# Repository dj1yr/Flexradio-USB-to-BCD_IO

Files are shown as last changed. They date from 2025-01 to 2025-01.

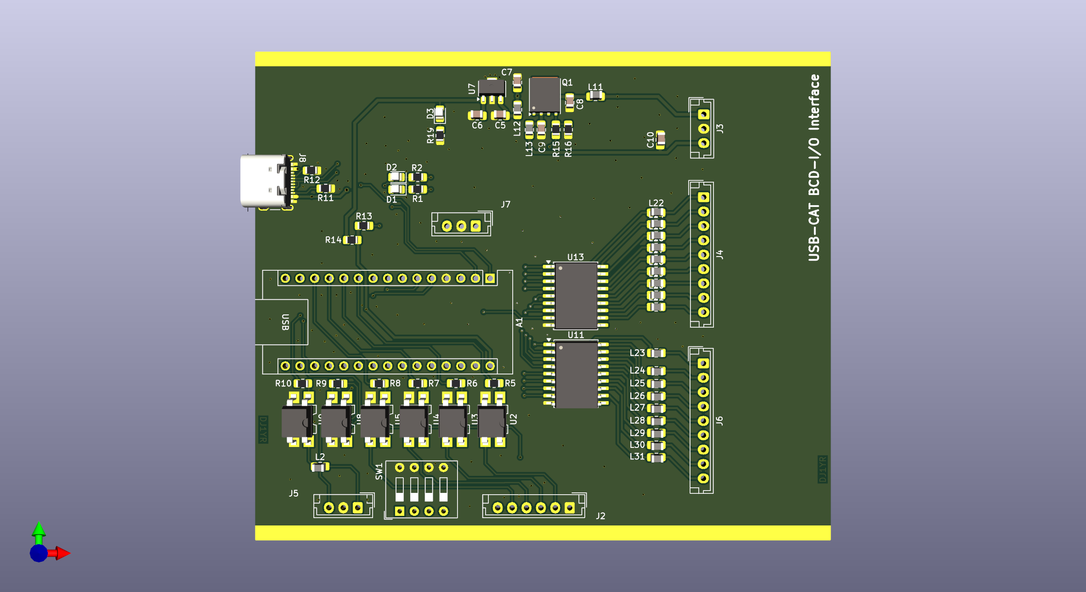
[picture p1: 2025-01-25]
Flexradio USB to BCD IO_top.png

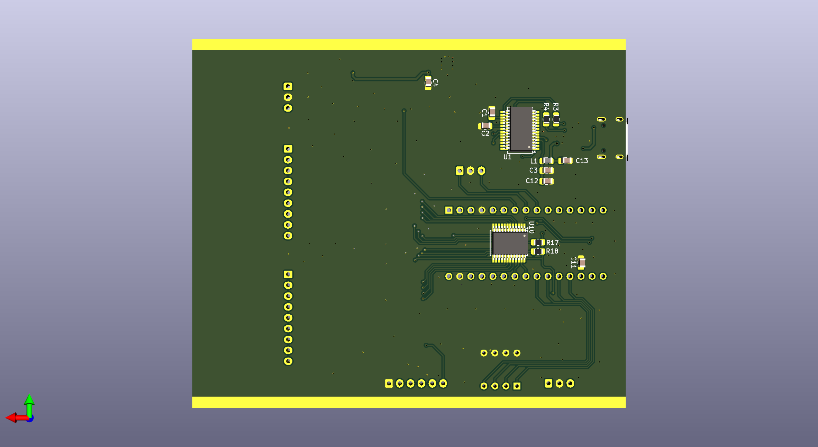
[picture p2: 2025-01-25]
Flexradio USB to BCD IO_bottom.png

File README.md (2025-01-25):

Since Flexradio does not output any band data from the device, the Flexwire bus unfortunately does not work. (is not implemented by Flex)
I have created a circuit board which adapts the USB signal to TTL to the Arduino Every.
The Flexradio only recognizes FTDI converters!
The board has BCD out, TXin and TXout, as well as 16 I/O via PCF8575 for other functions.
I need the board to control my VL-1000.

The software is currently under development and so far only reads and selects the data.

73' René

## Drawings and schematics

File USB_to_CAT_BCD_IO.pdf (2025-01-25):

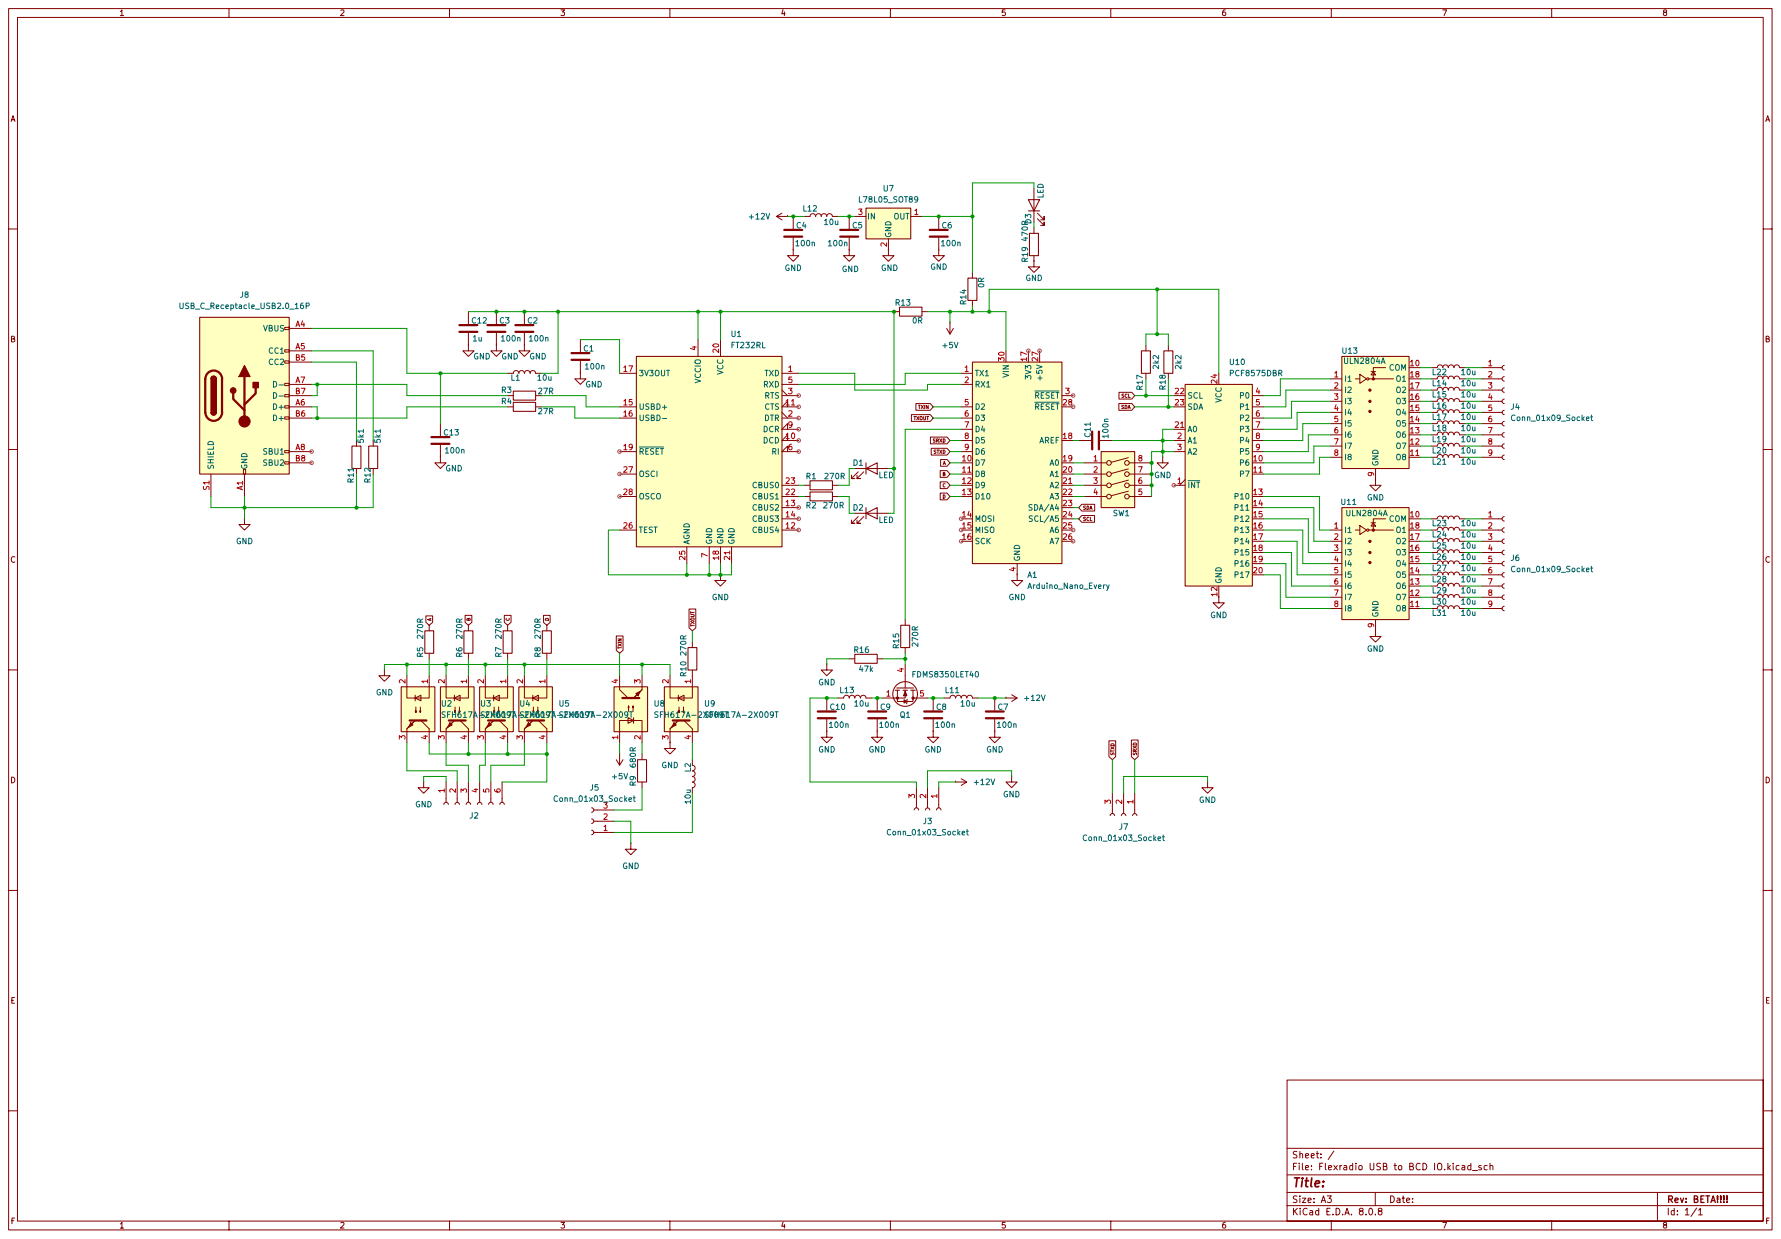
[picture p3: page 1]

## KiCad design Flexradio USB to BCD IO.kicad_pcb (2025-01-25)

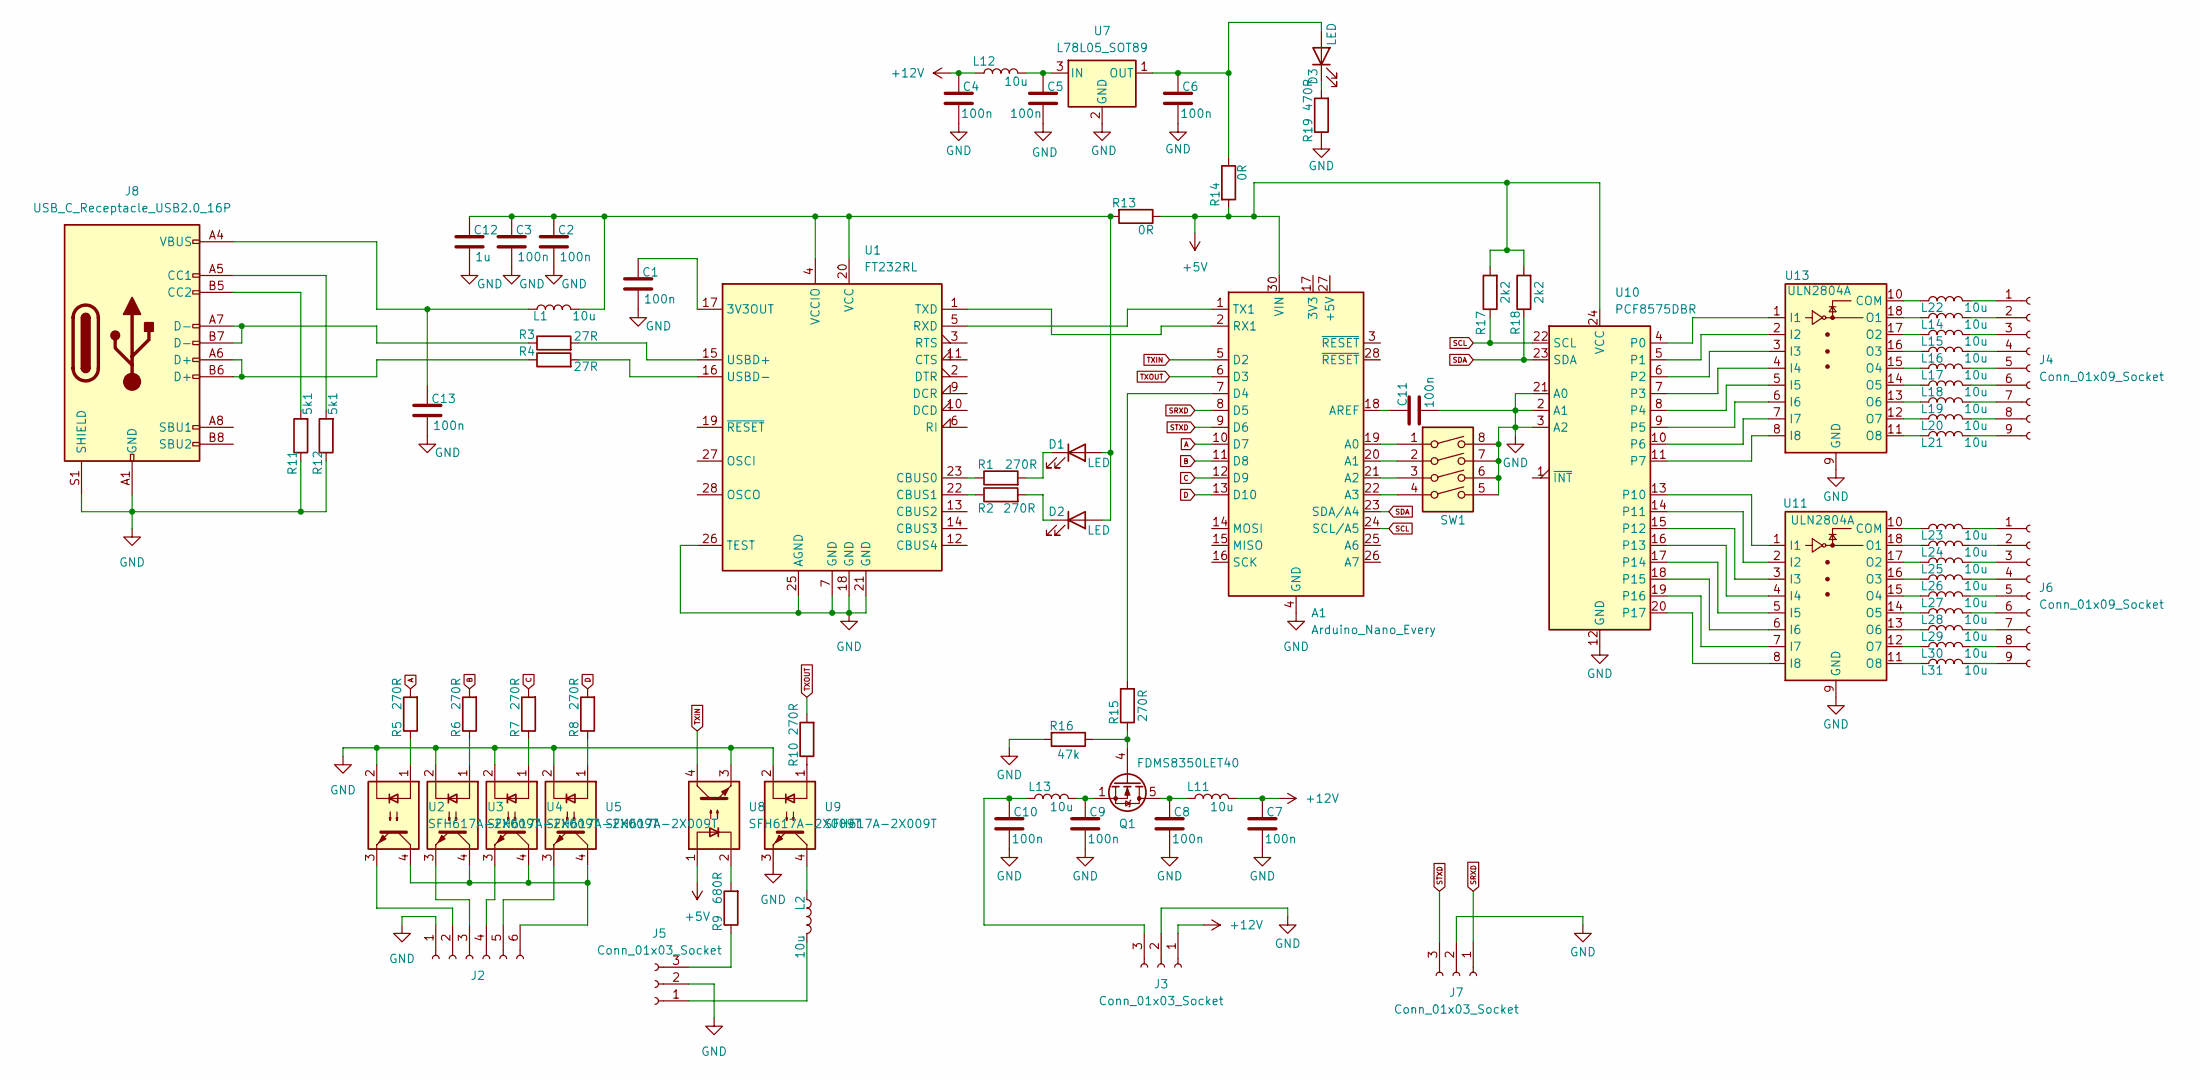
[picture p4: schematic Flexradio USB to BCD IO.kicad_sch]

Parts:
A1: Arduino_Nano_Every; Arduino_Nano
C1, C2, C3, C4, C5, C6, C7, C8, C9, C10, C11, C13: 100n; C_0805_2012Metric_Pad1.18x1.45mm_HandSolder
C12: 1u; C_0805_2012Metric_Pad1.18x1.45mm_HandSolder
D1, D2, D3: LED; LED_0805_2012Metric
J2: Conn_01x06_Socket; JST_EH_B6B-EH-A_1x06_P2.50mm_Vertical
J3, J5, J7: Conn_01x03_Socket; JST_EH_B3B-EH-A_1x03_P2.50mm_Vertical
J4, J6: Conn_01x09_Socket; JST_EH_B9B-EH-A_1x09_P2.50mm_Vertical
J8: USB_C_Receptacle_USB2.0_16P; USB_C_Receptacle_GCT_USB4105-xx-A_16P_TopMnt_Horizontal
L1, L2, L11, L12, L13, L14, L15, L16, L17, L18, L19, L20, L21, L22, L23, L24, L25, L26, L27, L28, L29, L30, L31: 10u; L_0805_2012Metric_Pad1.15x1.40mm_HandSolder
Q1: FDMS8350LET40; TDSON-8-1
R1, R2, R5, R6, R7, R8, R10, R15: 270R; R_0805_2012Metric_Pad1.20x1.40mm_HandSolder
R3, R4: 27R; R_0805_2012Metric_Pad1.20x1.40mm_HandSolder
R9: 680R; R_0805_2012Metric_Pad1.20x1.40mm_HandSolder
R11, R12: 5k1; R_0805_2012Metric_Pad1.20x1.40mm_HandSolder
R13, R14: 0R; R_0805_2012Metric_Pad1.20x1.40mm_HandSolder
R16: 47k; R_0805_2012Metric_Pad1.20x1.40mm_HandSolder
R17, R18: 2k2; R_0805_2012Metric_Pad1.20x1.40mm_HandSolder
R19: 470R; R_0805_2012Metric_Pad1.20x1.40mm_HandSolder
SW1: SW_DIP_x04; SW_DIP_SPSTx04_Slide_9.78x12.34mm_W7.62mm_P2.54mm
U1: FT232RL; SSOP-28_5.3x10.2mm_P0.65mm
U2, U3, U4, U5, U8, U9: SFH617A-2X009T; SMDIP-4_W7.62mm
U7: L78L05_SOT89; SOT-89-3
U10: PCF8575DBR; SSOP-24_5.3x8.2mm_P0.65mm
U11, U13: ULN2804A; SOIC-18W_7.5x11.6mm_P1.27mm

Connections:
+5V: A1.30 (VIN), R13.1, R14.2, R17.2, R18.2, U8.1, U10.24 (VCC)
+12V: C4.1, C7.1, J3.1, L11.2, L12.1
A: A1.10 (D7), R5.2
B: A1.11 (D8), R6.2
C: A1.12 (D9), R7.2
D: A1.13 (D10), R8.2
GND: A1.4 (GND), A1.29 (GND), C1.2, C2.2, C3.2, C4.2, C5.2, C6.2, C7.2, C8.2, C9.2, C10.2, C11.2, C12.2, C13.2, J2.1, J3.2, J5.2, J7.2, J8.A1 (GND), J8.A12 (GND), J8.B1 (GND), J8.B12 (GND), J8.S1 (SHIELD), R11.1, R12.1, R16.2, R19.1, SW1.5, SW1.6, SW1.7, SW1.8, U1.7 (GND), U1.18 (GND), U1.21 (GND), U1.25 (AGND), U1.26 (TEST), U2.2, U3.2, U4.2, U5.2, U7.2 (GND), U8.3, U9.2, U9.3, U10.2 (A1), U10.3 (A2), U10.12 (GND), U10.21 (A0), U11.9 (GND), U13.9 (GND)
unnamed: A1.19 (A0), SW1.1
unnamed: A1.20 (A1), SW1.2
unnamed: A1.21 (A2), SW1.3
unnamed: A1.22 (A3), SW1.4
unnamed: A1.18 (AREF), C11.1
unnamed: A1.7 (D4), R15.2
unnamed: A1.2 (RX1), U1.1 (TXD)
unnamed: A1.1 (TX1), U1.5 (RXD)
unnamed: C9.1, L13.2, Q1.1 (S), Q1.2 (S), Q1.3 (S)
unnamed: C13.1, J8.A4 (VBUS), J8.A9 (VBUS), J8.B4 (VBUS), J8.B9 (VBUS), L1.1
unnamed: C2.1, C3.1, C12.1, D1.2 (A), D2.2 (A), L1.2, R13.2, U1.4 (VCCIO), U1.20 (VCC)
unnamed: D1.1 (K), R1.2
unnamed: D2.1 (K), R2.2
unnamed: C6.1, D3.2 (A), R14.1, U7.1 (OUT)
unnamed: D3.1 (K), R19.2
unnamed: J2.2, U2.3
unnamed: J2.3, U3.3
unnamed: J2.4, U4.3
unnamed: J2.5, U5.3
unnamed: J2.6, U2.4, U3.4, U4.4, U5.4
unnamed: C10.1, J3.3, L13.1
unnamed: J4.1, L22.2
unnamed: J4.2, L14.2
unnamed: J4.3, L15.2
unnamed: J4.4, L16.2
unnamed: J4.5, L17.2
unnamed: J4.6, L18.2
unnamed: J4.7, L19.2
unnamed: J4.8, L20.2
unnamed: J4.9, L21.2
unnamed: J5.1, L2.2
unnamed: J5.3, R9.1
unnamed: J6.1, L23.2
unnamed: J6.2, L24.2
unnamed: J6.3, L25.2
unnamed: J6.4, L26.2
unnamed: J6.5, L27.2
unnamed: J6.6, L28.2
unnamed: J6.7, L29.2
unnamed: J6.8, L30.2
unnamed: J6.9, L31.2
unnamed: J8.A5 (CC1), R12.2
unnamed: J8.B5 (CC2), R11.2
unnamed: J8.A6 (D+), J8.B6 (D+), R4.1
unnamed: J8.A7 (D-), J8.B7 (D-), R3.1
unnamed: L2.1, U9.4
unnamed: C8.1, L11.1, Q1.5 (D)
unnamed: Q1.4 (G), R15.1, R16.1
unnamed: R5.1, U2.1
unnamed: R6.1, U3.1
unnamed: R7.1, U4.1
unnamed: R8.1, U5.1
unnamed: R9.2, U8.2
unnamed: R10.1, U9.1
unnamed: C1.1, U1.17 (3V3OUT)
unnamed: R1.1, U1.23 (CBUS0)
unnamed: R2.1, U1.22 (CBUS1)
unnamed: R3.2, U1.15 (USBD+)
unnamed: R4.2, U1.16 (USBD-)
unnamed: C5.1, L12.2, U7.3 (IN)
unnamed: U10.4 (P0), U13.1 (I1)
unnamed: U10.5 (P1), U13.2 (I2)
unnamed: U10.6 (P2), U13.3 (I3)
unnamed: U10.7 (P3), U13.4 (I4)
unnamed: U10.8 (P4), U13.5 (I5)
unnamed: U10.9 (P5), U13.6 (I6)
unnamed: U10.10 (P6), U13.7 (I7)
unnamed: U10.11 (P7), U13.8 (I8)
unnamed: U10.13 (P10), U11.1 (I1)
unnamed: U10.14 (P11), U11.2 (I2)
unnamed: U10.15 (P12), U11.3 (I3)
unnamed: U10.16 (P13), U11.4 (I4)
unnamed: U10.17 (P14), U11.5 (I5)
unnamed: U10.18 (P15), U11.6 (I6)
unnamed: U10.19 (P16), U11.7 (I7)
unnamed: U10.20 (P17), U11.8 (I8)
unnamed: L23.1, U11.10 (COM)
unnamed: L24.1, U11.18 (O1)
unnamed: L25.1, U11.17 (O2)
unnamed: L26.1, U11.16 (O3)
unnamed: L27.1, U11.15 (O4)
unnamed: L28.1, U11.14 (O5)
unnamed: L29.1, U11.13 (O6)
unnamed: L30.1, U11.12 (O7)
unnamed: L31.1, U11.11 (O8)
unnamed: L22.1, U13.10 (COM)
unnamed: L14.1, U13.18 (O1)
unnamed: L15.1, U13.17 (O2)
unnamed: L16.1, U13.16 (O3)
unnamed: L17.1, U13.15 (O4)
unnamed: L18.1, U13.14 (O5)
unnamed: L19.1, U13.13 (O6)
unnamed: L20.1, U13.12 (O7)
unnamed: L21.1, U13.11 (O8)
SCL: A1.24 (SCL/A5), R17.1, U10.22 (SCL)
SDA: A1.23 (SDA/A4), R18.1, U10.23 (SDA)
SRXD: A1.8 (D5), J7.1
STXD: A1.9 (D6), J7.3
TXIN: A1.5 (D2), U8.4
TXOUT: A1.6 (D3), R10.2

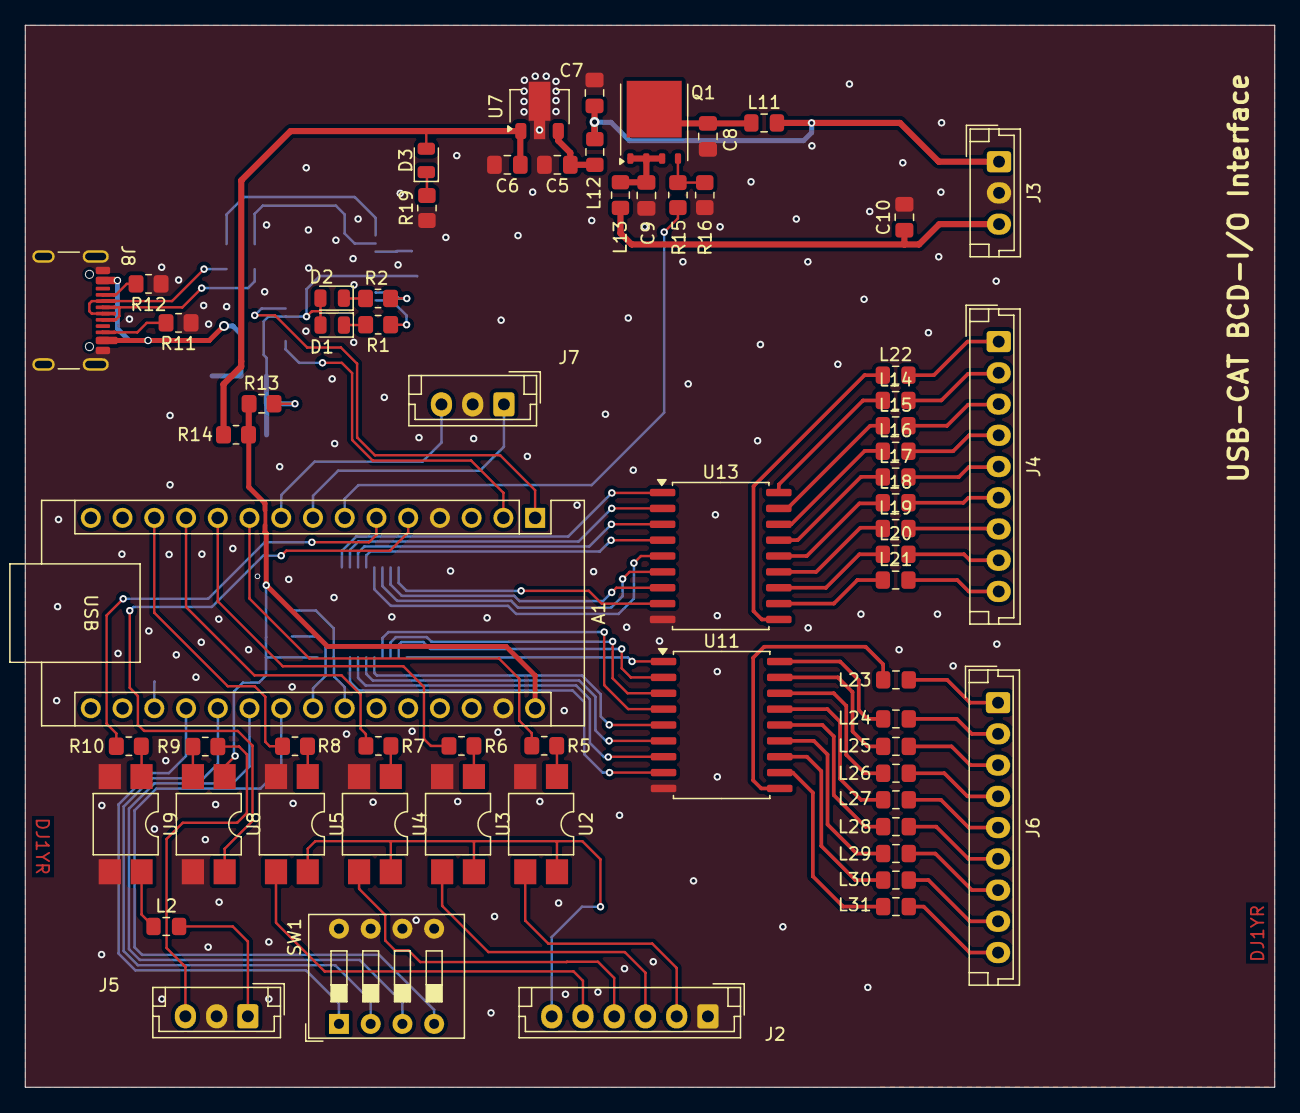
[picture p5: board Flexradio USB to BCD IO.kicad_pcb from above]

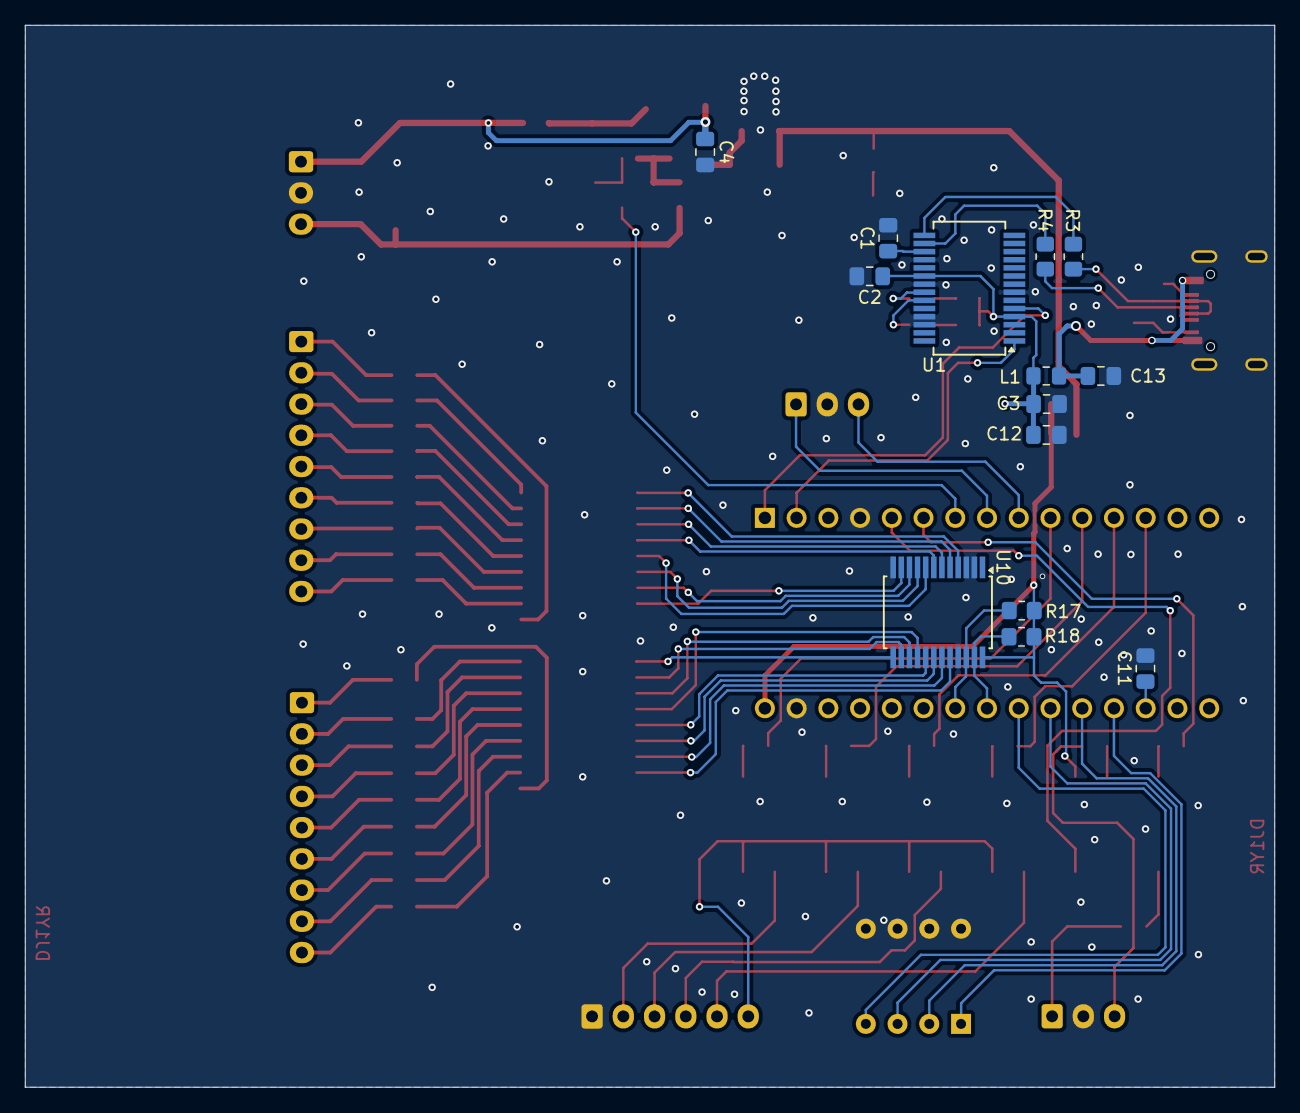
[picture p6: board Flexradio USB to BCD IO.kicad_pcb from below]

Board: 2 copper layers, 100.0 x 85.0 mm, 79 parts (14 on the bottom side), 107 nets.

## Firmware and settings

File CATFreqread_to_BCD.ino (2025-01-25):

/* this software is alpha!!
only CAT Data read from Flex 6x00
*/


#include "Arduino.h"
#include "PCF8575.h"          // https://github.com/xreef/PCF8575_library
#include <SoftwareSerial.h>

SoftwareSerial cat_ser(5, 6); // RX, TX

PCF8575 pcf8575(0x20);


char inputByte;  
String inputbuffer = "";  
bool readComplete = false; 

byte band = 9;
int A = 7;
int B = 8;
int C = 9;
int D = 10; 

bool TX_in = 2;
bool TX_out = 3;
int TX_ok = false;

bool pcf_a0;
bool pcf_a1;
bool pcf_a2;
bool pcf_a3;
bool pcf_a4;
bool pcf_a5;
bool pcf_a6;
bool pcf_a7;

bool pcf_b0;
bool pcf_b1;
bool pcf_b2;
bool pcf_b3;
bool pcf_b4;
bool pcf_b5;
bool pcf_b6;
bool pcf_b7;
byte pcf_a;
byte pcf_b;

byte bcdoutputPins[] {7,8,9,10};

/*byte yaesu_bcd [16][4]={   //BCD table -- yaesu_bcd [band][A,B,C;D]
{0,0,0,0},
{0,0,0,1},    //160m
{0,0,1,0},    //80m
{0,0,1,1},    //60/40m
{0,1,0,0},    //30m
{0,1,0,1},    //20m
{0,1,1,0},    //17m
{0,1,1,1},    //15m
{1,0,0,0},    //12m
{1,0,0,1},    //10m
{1,0,1,0},    //6m
{1,0,1,1},    //4m
{1,1,0,0},    //2m
{1,1,0,1},    //70cm
{1,1,1,0},    //23cm
{1,1,1,1},
};*/



float yaesu_bcd [16][4]={   //BCD table -- yaesu_bcd [band][A,B,C;D]
{A=0,B=0,C=0,D=0},
{A=0,B=0,C=0,D=1},    //160m
{A=0,B=0,C=1,D=0},    //80m
{A=0,B=0,C=1,D=1},    //60/40m
{A=0,B=1,C=0,D=0},    //30m
{A=0,B=1,C=0,D=1},    //20m
{A=0,B=1,C=1,D=0},    //17m
{A=0,B=1,C=1,D=1},    //15m
{A=1,B=0,C=0,D=0},    //12m
{A=1,B=0,C=0,D=1},    //10m
{A=1,B=0,C=1,D=0},    //6m
{A=1,B=0,C=1,D=1},    //4m
{A=1,B=1,C=0,D=0},    //2m
{A=1,B=1,C=0,D=1},    //70cm
{A=1,B=1,C=1,D=0},    //23cm
{A=1,B=1,C=1,D=1},
};

void setup(){
  Serial.begin(9600);       //Debug Serial
  Serial1.begin(9600);      //CAT Serial Flex
  cat_ser.begin(9600);      //CAT Serial optional

// pinMode BCD
  pinMode(A, OUTPUT);
  pinMode(B, OUTPUT);
  pinMode(C, OUTPUT);
  pinMode(D, OUTPUT);
//  pinMode TX
  pinMode(TX_in, INPUT_PULLUP);
  pinMode(TX_out, OUTPUT); 
// PCF8575
  // Set pinMode to OUTPUT
  for(int i=0;i<16;i++) {
    pcf8575.pinMode(i, OUTPUT);
  }
  pcf8575.begin();

}   //end setup

void loop() {


      if (Serial1.available() > 0) {
        inputByte = (char) Serial1.read(); 
        inputbuffer += inputByte; 
        if (inputByte == ';') {
        readComplete = true; 
        }
      }

    
    if (readComplete) {
        String input_str = inputbuffer;
        String freq ;
        freq = input_str.substring(4,13);


    if (freq>= "470000000"){          // 23cm Band selcted
      band = 14;
      bcdoutputPins[4] = band;}
          else if (freq >= "150000000"){  // 70cm Band selcted
        band = 13;
        bcdoutputPins[4] = band;}  
      else if (freq >= "074000000"){  // 2m Band selcted
        band = 12;
        bcdoutputPins[4] = band;}      
      else if (freq >= "054000000"){  // 4m Band selcted
        band = 11;
        bcdoutputPins[4] = band;}      
      else if (freq >= "030000000"){  // 6m Band selcted
        band = 10;
        bcdoutputPins[4] = band;}
      else if (freq >= "028000000"){  // 10m Band selcted
        band = 9;
        bcdoutputPins[4] = band;}        
      else if (freq >= "024000000"){  // 12 Band selcted
        band = 8;
        bcdoutputPins[4] = band;}
      else if (freq >= "020000000"){  // 15m Band selcted
        band = 7;
        bcdoutputPins[4] = band;}
      else if (freq >= "015000000"){  // 17m Band selcted  
        band = 6;
        bcdoutputPins[4] = band;}
      else if (freq >= "012000000"){  // 20m Band selcted
        band = 5;
        bcdoutputPins[4] = band;}        
      else if (freq >= "009000000"){  // 30 Band selcted
        band = 4;
        bcdoutputPins[4] = band;}
      else if (freq >= "005000000"){  // 60/40m Band selcted
        band = 3;
        bcdoutputPins[4] = band;}
      else if (freq >= "002000000"){  // 80m Band selcted
        band = 2;
        bcdoutputPins[4] = band;}
      else if (freq >= "001700000"){  // 160m Band selcted
        band = 1;
        bcdoutputPins[4] = band;}        
      else {
        band = 0;
        bcdoutputPins[4] = band;}                    // no Band selcted  

        Serial.print("freq_Hz=");
        Serial.println(freq);
        Serial.print("Band=");
        Serial.println(band);
        Serial.print("Outputbyte=");
        Serial.println(bcdoutputPins[4], BIN);
        Serial.flush();
        pcf8575_write();
        
        inputbuffer = "";
        readComplete = false; 
      }

    if (band = 0){
        TX_ok = false;}
      else {
        TX_ok = true;}  

    if((TX_ok)&&digitalRead(TX_in==LOW)){
        digitalWrite(TX_out,HIGH);}
      else{
        digitalWrite(TX_out,LOW);}    

  } //end loop

//Test############################
  void pcf8575_write() {
  static int pin = 0;
  /*pcf8575.digitalWrite(pin, HIGH);
  delay(100);
  pcf8575.digitalWrite(pin, LOW);
  delay(100);
  pin++;
  if (pin > 15) pin = 0;*/

      digitalWrite(A,A);
      digitalWrite(B,B);
      digitalWrite(C,C);
      digitalWrite(D,D);

  } //end subloop
